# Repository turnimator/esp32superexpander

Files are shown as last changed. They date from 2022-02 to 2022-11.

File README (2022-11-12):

ESP32Superexpander.2ndattempt  - Previous hardware definition (KiCad) files
ESP32forth-7-Superexpander-0.1 - Arduino sketch containing a Superexpander ESPforth version
ESP32superexpander       -  The current Kicad files
Superexpander            - Arduino library for Suoerexpander
SuperExpander.odt        - A description of the project
superexpanderSupport.c   - Code to add to ESP32forth 

A document explaining the Forth code:

https://docs.google.com/document/d/1MlfXAm6yeVxjHgzF-E0LGG0kIZ7gFkiAXZAdYF-DrEk/edit?usp=sharing

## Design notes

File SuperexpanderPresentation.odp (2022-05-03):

## Requirements

- If your robot about to crash or drive off an edge, it must stop immediately
  For this you need IR sensors all around the the body, and ideally, underneath as well.
- In order to keep the robot from veering left or right, you need to know how far each wheel has traveled
  For this you need at least two disc encoders with optical sensors
- As your project progresses, you’ll want to add more features.
  For less than 8$, you can get a box with 37 sensors, most of which could be useful, or at least fun to add.
  Buzzers, Movement detectors (are the wheels spinning?), relays, color detectors (for line following and more), tilt switches, temperature sensors, sound detectors, shock detectors, humidity detectors (we don’t want to get wet!)
  Combining multiple input types, you can make inferences about the state of the robot and its environment.
  The more capabilities you add, the more awesome your robot becomes
- However ...

## Limitations

- … the ESP32 has 36 IO pins This may seem like a lot at first, but as you add sensors, distance measuring, GPS, … you’ll find the number of free pins dwindeling faster than the money in an average pensioner’s bank account
- In order to connect all your devices to the ESP32, you will have to make some kind of mainboard anyway, so why not solve two problems at once?

## ESP32 Superexpander

The ESP32 Superexpander gives you

- 3 headers for VL53L0X laser distance meters
- 4 I²C headers
- 2 headers for wheel motion IR sensors
- 1 header for L298 or compatible motor driver
- 12 on-off outputs for relays, switches, …
- 8 on-off inputs for sensors
- 12 breakouts for GPIO pins

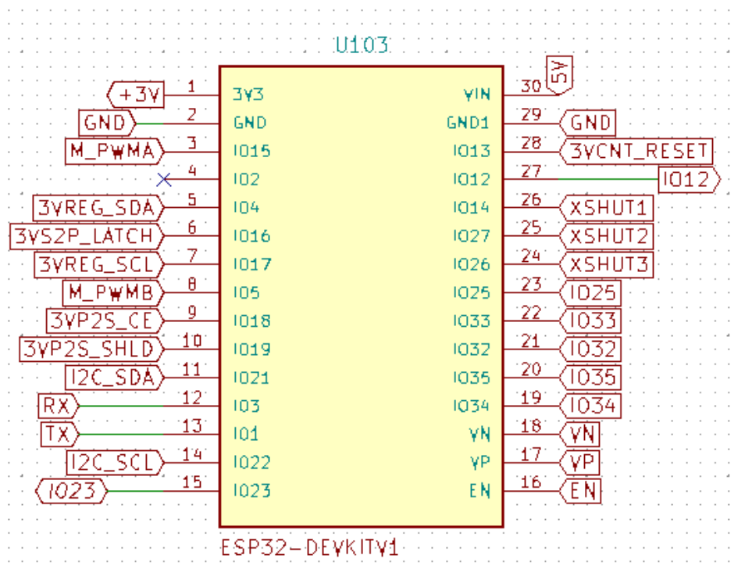
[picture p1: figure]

## Counters

- For some input, we need to know immediately if it goes active, e.g. an imminent crash or other catastrophe. An Interrupt Service Routine must set a variable and disable the motor before returning.
- For other inputs, like wheel motion, it’s enough to know how far we’ve traveled on each iteration. However, wheel motion arrives in tiny millimeter increments, and when driving at full speed, they arrive too fast for us to poll them. We need one interrupt handler for the left wheel and one for the right, updating two variables that we can read on each iteration. With all the other stuff that will be going on, reading a compass, reading lasers, communicating telemetry over UDP, avoiding obstacles, calculating trajectories, …. having two ISRs just for keeping track of wheel motion seems like an awful waste of resources.
- Why not offload the millimeter counting to a special purpose circuit like the 4060 and the read the count from a register on each iteration?

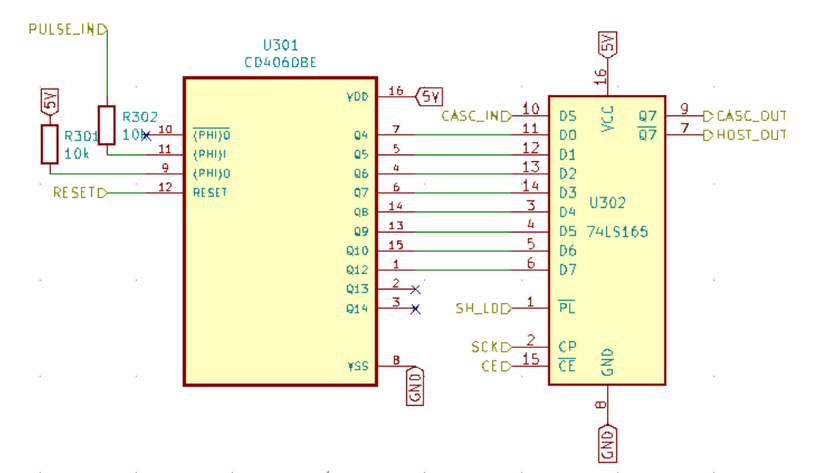
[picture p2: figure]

## Design

- Putting it all together in KiCad, you might get something like this

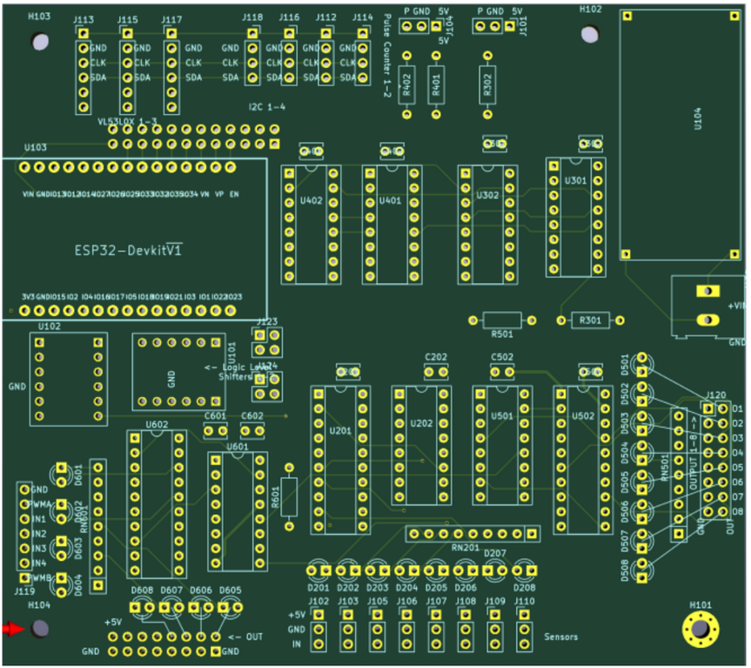
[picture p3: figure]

## BLINKENLIGHTS!!!

- … and, if you’re not careful when selecting resistor values for the LEDs, when you hook it up and turn on the power, it will look like this (which is what I wanted anyway because I’m crazy):

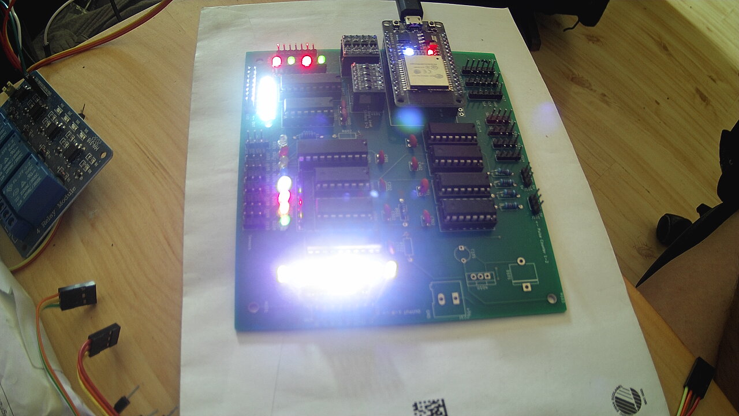
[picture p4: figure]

## Outputs

- Blink all outputs  Step through all 16 outputs, turning them on and off in sequence
  : blinkoutputs
  16 0 DO
  i outputon writeboard
  100 ms
  i outputoff writeboard
  100 ms
  LOOP
  ;

## Outputon

- The output number n must be on the stack
- If n is less than 8, set the nth bit in the value outreg1
- Else set the (8-n)th bit of outreg2
- Write the values of outreg1 and outreg2 to the board using writeS2P

: outputOn ( u -- )

dup 8 < IF

1 swap lshift outreg1 or to outreg1

ELSE

1 swap 8 - lshift outreg2 or to outreg2

THEN

;

## Gear_forward, Gear_backward

- Forward: Set bits 0 and 2, clear bits 1 and 3 in outreg1 without touching other bits
- Backward: Set bits 1 and 3, clear bits 0 and 2 in outreg1 without touching other bits

: gear_forward

binary

outreg1 10101111 and 10100000 or to outreg1

decimal

;

: gear_backward

binary

outreg1 01011111 and 01010000 or to outreg1

decimal

;

## WriteS2P

- Stack contains the two registers to be written
- Clear the LATCH
- Write the first
- Write the second
- Set the LATCH bit

S2P_LATCH 0 digitalWrite

8 0 DO

dup 1 and

S2P_SCL 0 digitalWrite

S2P_SDA swap digitalWrite

S2P_SCL 1 digitalWrite

1 RSHIFT

LOOP

Drop

…

S2P_LATCH 1 digitalWrite

## Inputs

- 2 counters
- 8 binary inputs
- Use readP2S to read (leaves three numbers on the stack)

## Showboard

- Show the status of the inputs
  NB: The inputs are inverted, 1 means 0 and 0 means 1. Counter value = 255-value.

: showBoard

readp2s

." Inputs " binary . cr

." Left wheel " decimal 255 swap - . cr

." Right wheel " 255 swap - . cr

;

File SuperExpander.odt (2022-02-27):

The ESP32 Superexpander

The ESP32 has 40 GPIO pins. If all you want to do is build a rover like the Forthmobile, that seems like a lot of pins, until you consider that 6 of them are used for the internal flash, one is used for debug, another is connected to the on-board LED, one will make the system fail if pulled high during boot, 4 are input only, and 4 of them produce a PWM signal at boot which might disturb your connected logic.

Only 14 pins don’t have any notes attached.

Out of these, you’ll need 2 for I2C clock and data, and if you’re planning to make use of the Forthmobile’s 3 VL53L0X laser distance sensors, you’re left with 9.

7 if you plan to use a GPS module. Perhaps you want two collision sensors at the front and two at the back? Now, you’ve got three pins left out of 40.

If you’re anything like me, you have a box full of cool sensors that you want to add: Movement detectors, sound, shock, and tilt detectors … temperature readers, line followers, buzzer and if you’re going to get anywhere at all, you need a motor controller, requiring an IN1, IN2, IN3, IN4 and two pwm pins.

A headlight switch would be nice to have as well, but you ran out of pins a couple of sensors ago.

Luckily, we can send data over a serial line to read to or write from an 8 bit register giving us 8 more pins minus the pins used for transmission, and if we cascade these registers, we get 16 extra pins instead of 8.

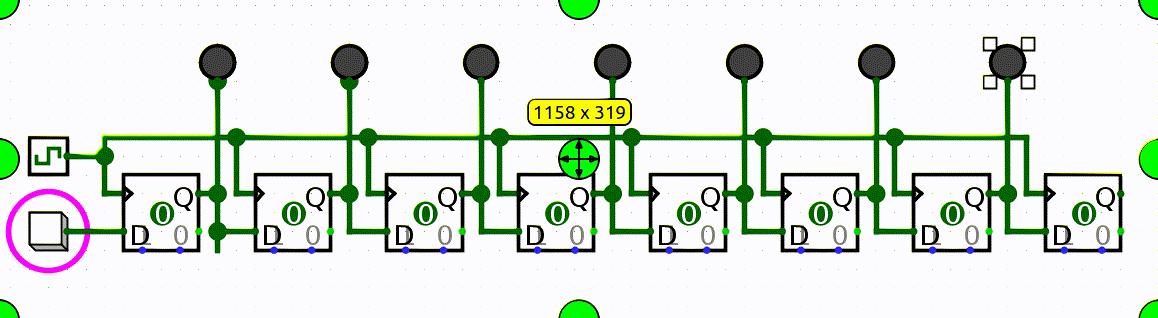
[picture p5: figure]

In the image above, when the square button in the lower left corner is pressed, a 1 is shifted in fron the left. When it’s released, a 0 is shifted in.

The ESP32 Superexpander uses five such registers, three 74LS165 for input and two 75LS595 for output.

Afferent flows

Two of the three 74165 input registers are connected to 4060 pulse counters.

Since the Superexpander is intended to be used as a main plate for a Forthmobile rover, the idea behind the counter registers is to let you keep track of your travel distance without using up two precious ESP32 interrupts.

The pulses are counted and stored in the 4060.

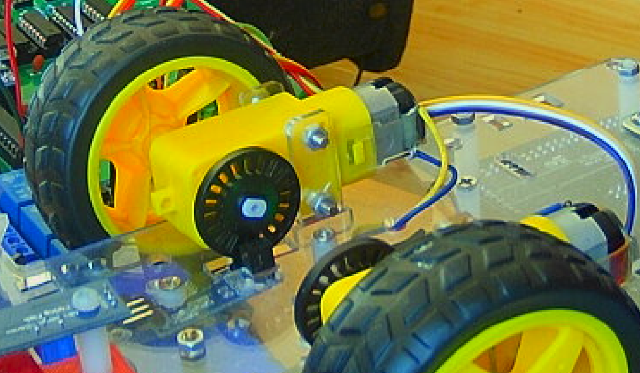
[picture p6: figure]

Figure 1: Mounted on the inside of the wheel is a disk with 24 slits in it. On the other side of the chassis there’s a pulse counter consisting of an LED and a photo transistor. Each time a slit passes over the LED, a pulse is generated.

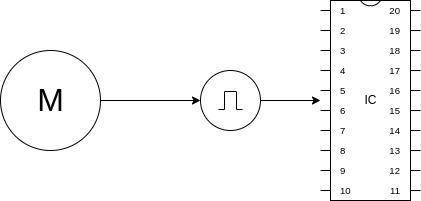
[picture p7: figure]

Whenever you want to read the value, you transfer the count from the 4060 to the 74165 using a LOAD signal (shown below as SH_LD) then read it serially into a variable inside the ESP32 using CLOCK and DATA signals, shown as SCK and HOST_OUT below.

Modules like the one above can be daisy-chained.

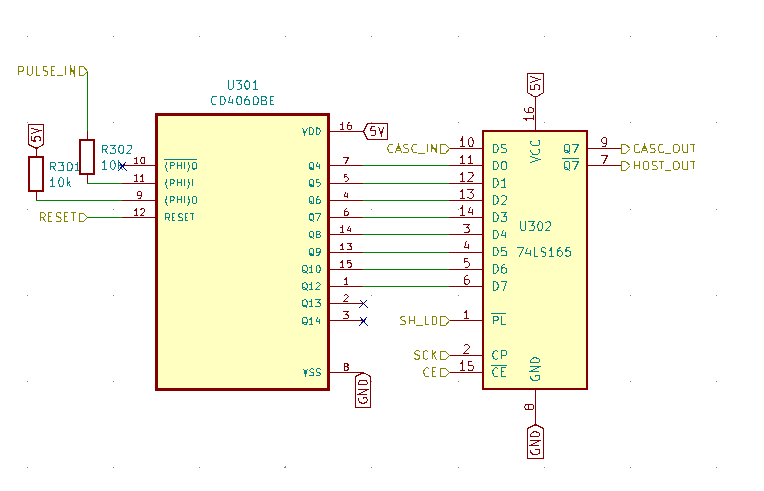
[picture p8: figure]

Figure 2: Counter module. When SH_LD is pulled LOW, data is transferred from the 4060 counter to the 74LS165 PISO register

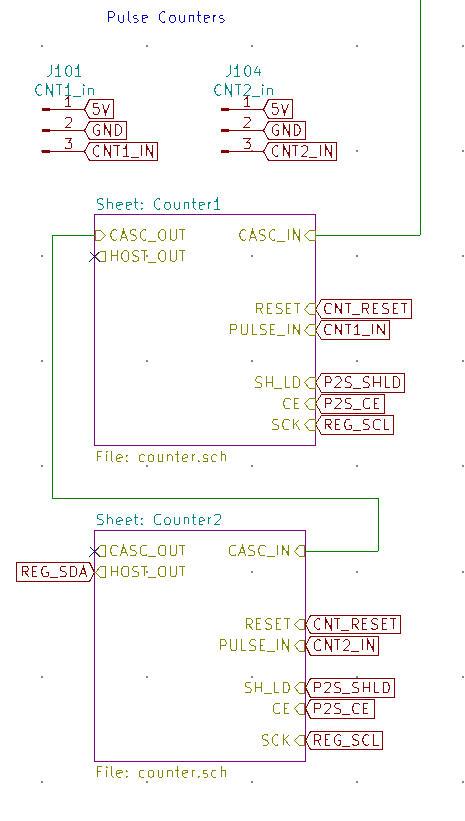
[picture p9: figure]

Figure 3: When daisy-chaining registers, serial output from one register is fed to the input of the next

The connectors J101 and J104 are meant for a pulse counter like the one below. The connections are as follows: VCC on the sensor to 5V on the module, GND to GND, and D0 CNT1_IN or CNT2_IN.

The A0 line is not used.

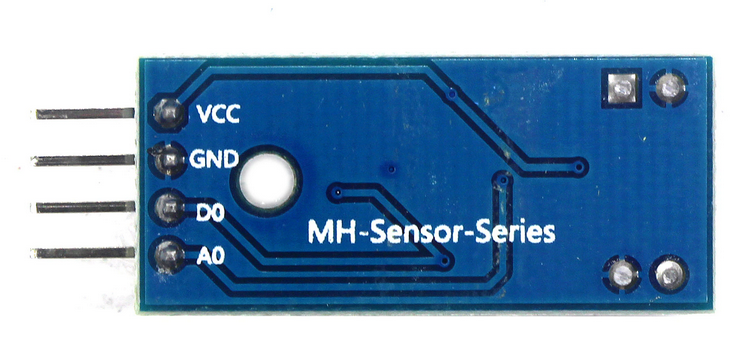
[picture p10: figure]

The CASC_IN line at the top of the counter module schematic comes from a sensor reading module.

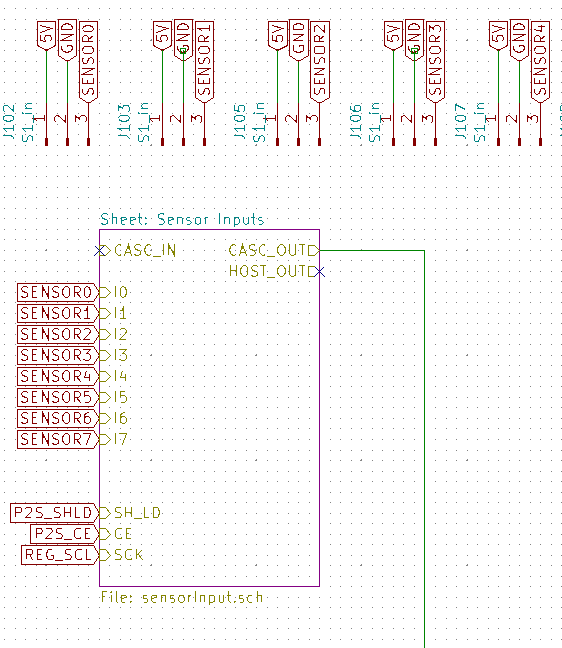
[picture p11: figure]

Figure 4: Here, you see the line CASC_OUT leaving the sensor schematic to enter as CASC_IN in the first counter module. The sensors are connected in the same way. Sensor VCC to 5V, GND to GND and the sensor output to one of the terminals labeled SENSOR0 through SENSOR7.

The inside of the module should be unsurprising. Instead of reading counter values, the 74165 reads the state of 8 input terminals, each corresponding to the output of one sensor.

The module also contains 8 LEDs that will light up on the board as soon as an input is activated.

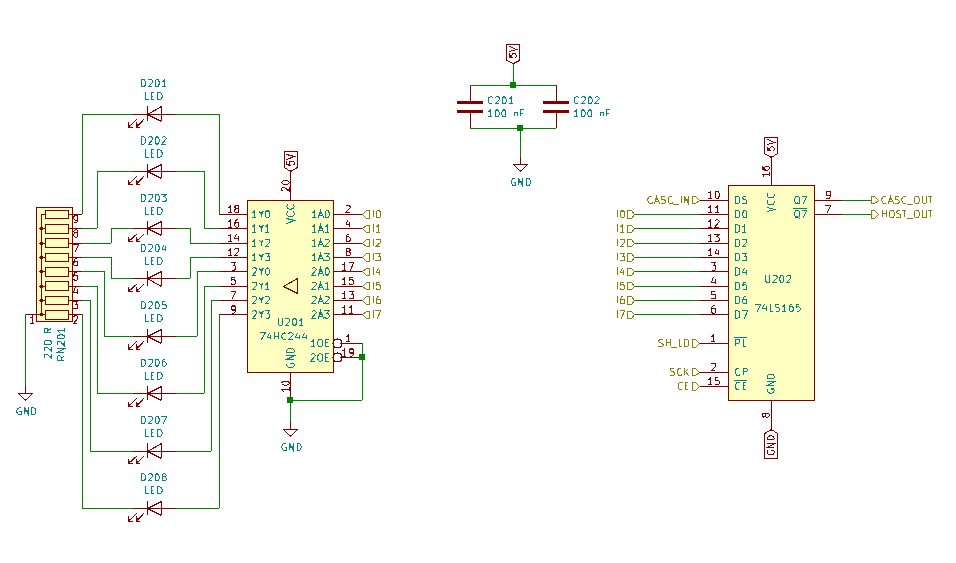
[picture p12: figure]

Figure 5: Sensor reading module. Data coming in on lines I0-I7 are split between the 74LS165 PISO register and an output buffer driving 7 LEDs.

Efferent flows

The output side consists of two output modules, cascaded in the same way as the input modules.

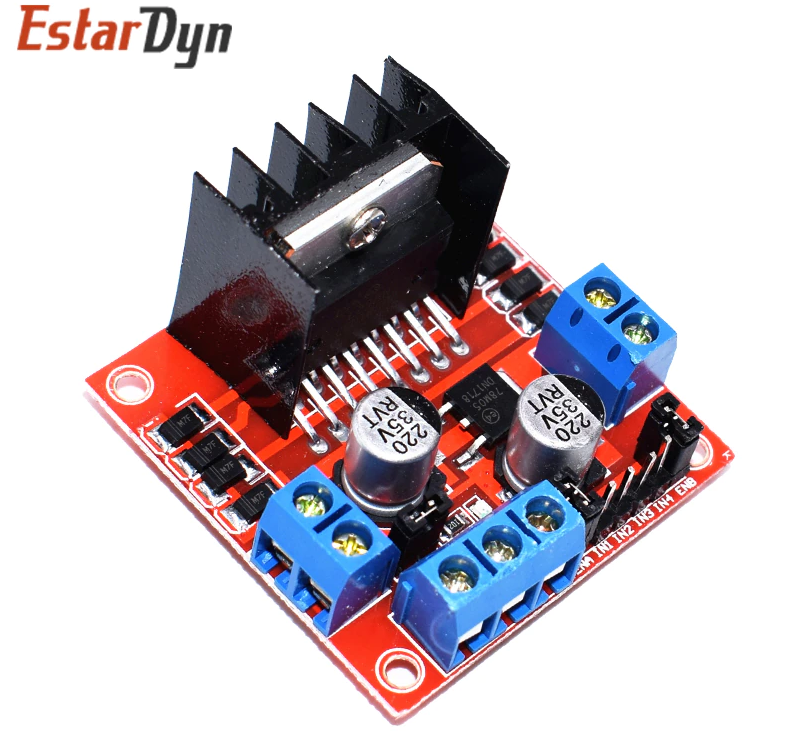
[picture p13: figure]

The connectors J120 and J121 give a total of 12 general purpose outputs plus 4x5V outputs.

The connector J119 is intended for an L298 motor driver shield, or any other shield with the same interface.

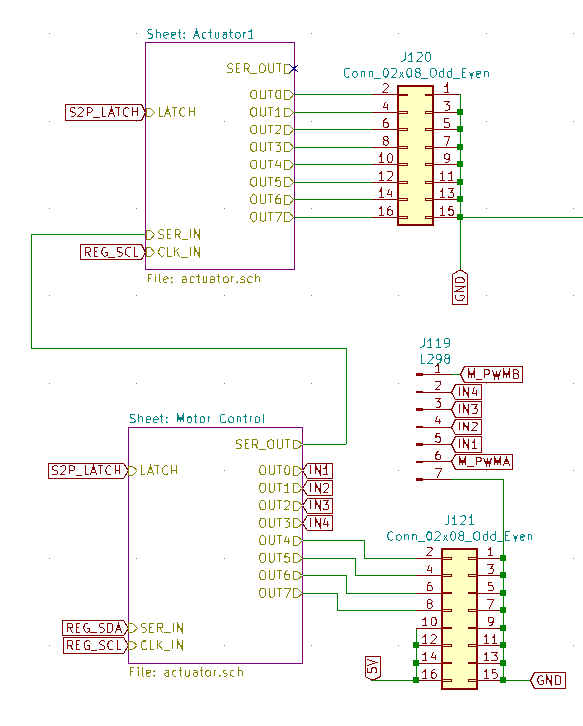
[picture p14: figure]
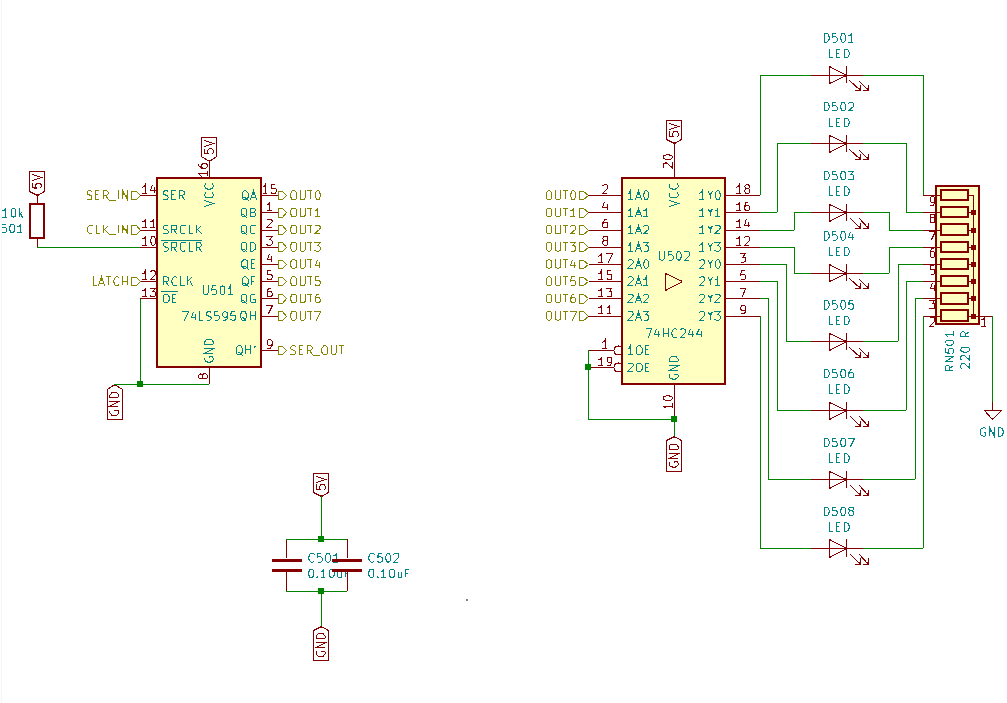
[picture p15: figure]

The outputs IN1 through IN4 get connected to IN1-IN4 on the shield, M_PWMA goes to ENA, and M_PWMB goes to ENB.

The inside of an actuator module is similar to that of the sensor module, with one LED per output for visual feedback.

Transformations

Last but not least, the star of the show: The ESP32 Devkit V1,

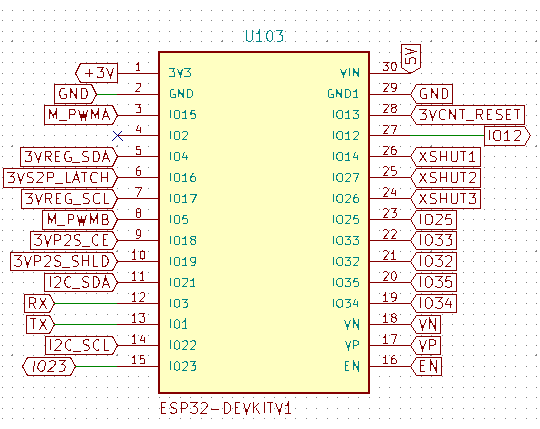
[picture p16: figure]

supported by two BOB-12009 level shifter modules to enable working with the more common 5V modules.

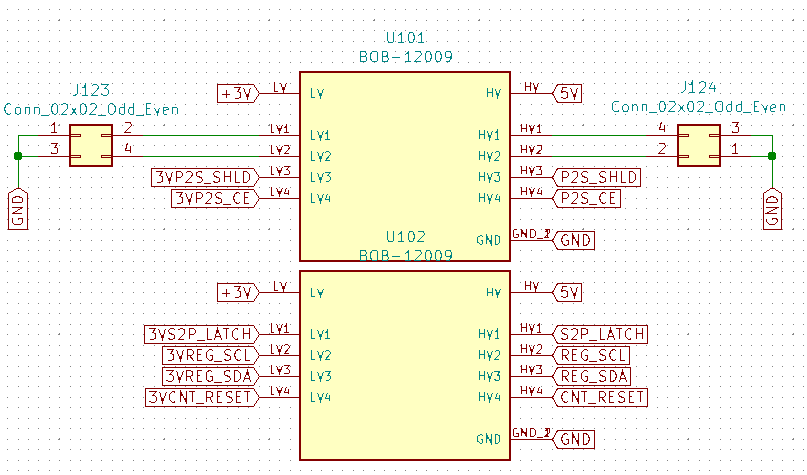
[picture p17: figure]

Figure 6: All the labels prefixed with 3V are connected to the ESP32 and the 3V side of the level shifters,

and the corresponding 5V side of the level shifter is connected to the register.

This is how the 3.3V ESP32 can drive 5V registers.

In addition to the connectors used for SIPO (serial-in, parallel out) and PISO registers, there are seven connectors giving access to the I2C bus. Three of them are intended for the LV53L0X laser distance sensor.

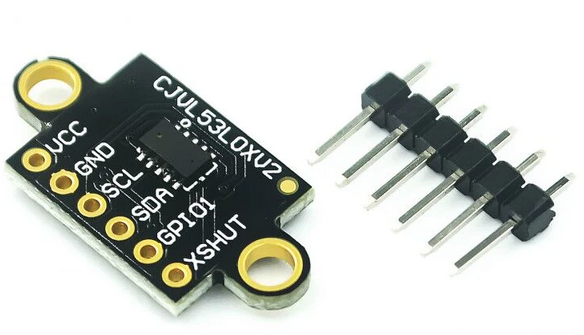
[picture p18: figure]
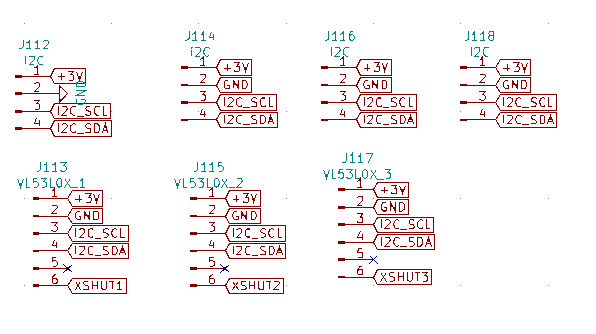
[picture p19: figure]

Putting it all together, the result becomes something like this:

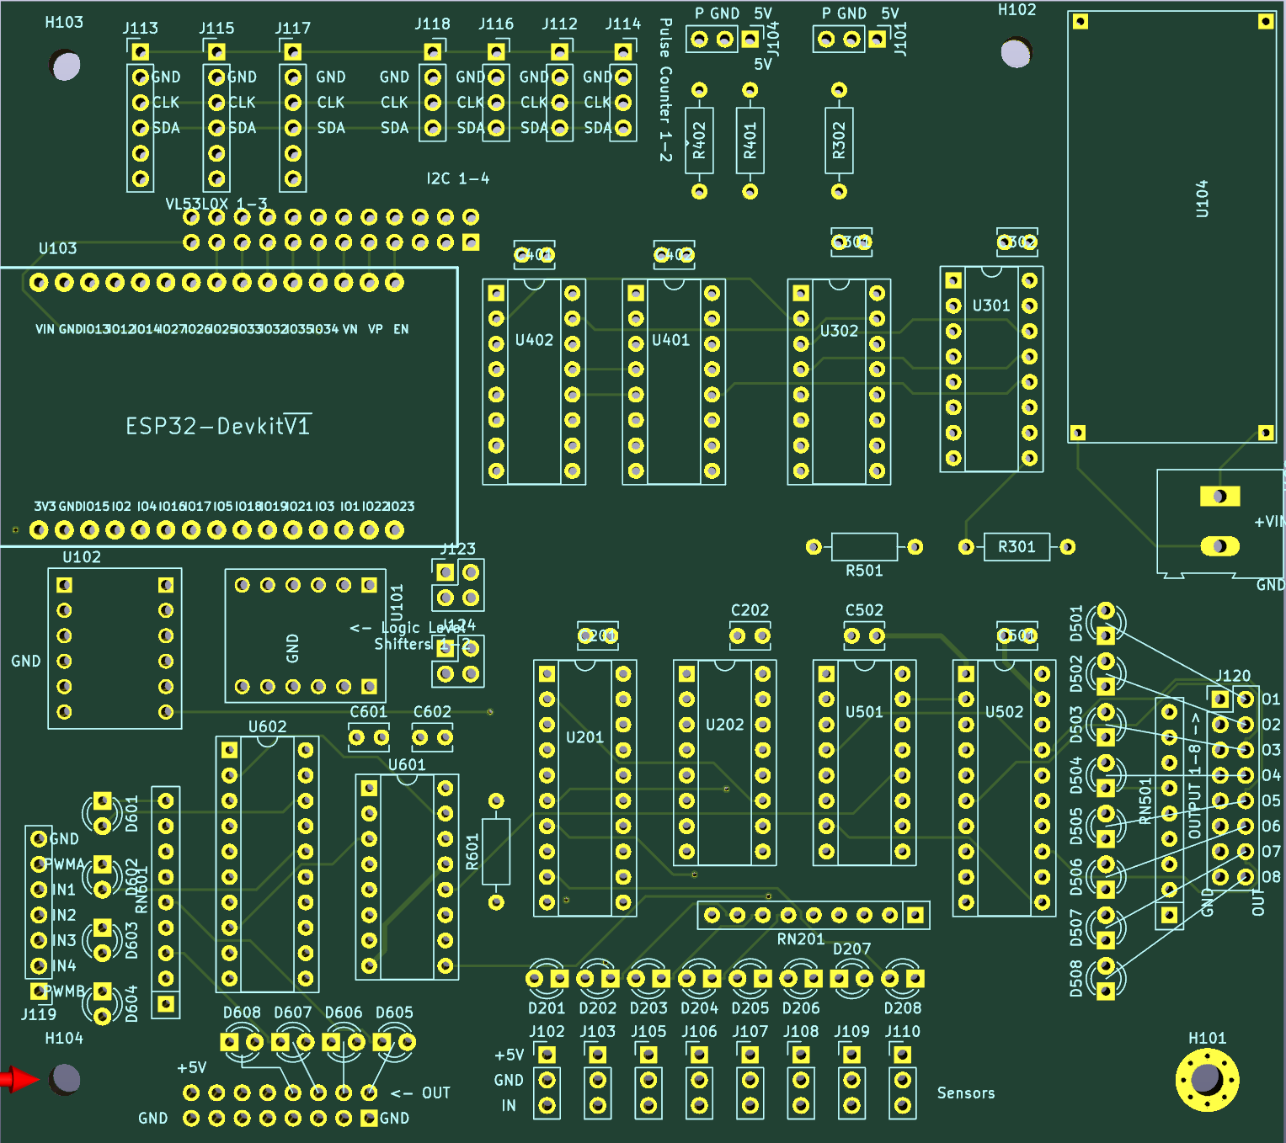
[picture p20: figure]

Directly above the ESP32 Devkit V1 module you find J111, a breakout of all the unused pins on the ESP32, 12 in all.

Programming

Constants

2 constant LED_BUILTIN

\ 74165 Parallel to serial

18 constant P2S_CE \ set high when P2S_SCK is HIGH to disable clock

19 constant P2S_SHLD \ Shift=1, load=0

17 constant P2S_SCK

23 constant P2S_SDA

\ 74595 Serial to parallel

4 constant S2P_SDA

16 constant S2P_LATCH \ aka RCLK

17 constant S2P_SCL

\ Motor control

15 constant M_PWMA

5 constant M_PWMB

\ LSB 0-3 of S2P give IN1-IN4 on the L298 motor controller connected to J15

21 constant I2C_SDA

22 constant I2C_SCL

13 constant CNT_RESET \ Reset the pulse counters on J21 and J22

\ VL53L0X uses I2C. To initialize, only keep one of these high and the

\ others LOW until the addresses are set. When the I2C address is set, all of these should be HIGH

14 constant XSHUT1

27 constant XSHUT2

26 constant XSHUT3

Setup

\ PISO REGISTERS

P2S_SHLD output pinMode

P2S_CE output pinMode

P2S_SCK output pinMode

P2S_SDA input pinMode

CNT_RESET output pinMode

CNT_RESET 0 digitalWrite 0 ms

CNT_RESET 1 digitalWrite 0 ms

CNT_RESET 0 digitalWrite

LED_BUILTIN output pinMode

P2S_SHLD output pinMode

P2S_CE output pinMode

P2S_SCK output pinMode

P2S_SDA input pinMode

Reading the PISO registers

: readP2S ( - n n n )

P2S_SHLD 0 digitalWrite 0 ms \ load data

P2S_SHLD 1 digitalWrite 0 ms \ prepare to shift

P2S_SCK 1 digitalWrite

P2S_CE 0 digitalWrite

P2S_SCK 0 digitalWrite

0

8 0 DO

1 LSHIFT

P2S_SCK 0 digitalWrite

P2S_SDA digitalRead OR

P2S_SCK 1 digitalWrite

LOOP

0

8 0 DO

1 LSHIFT

P2S_SCK 0 digitalWrite

P2S_SDA digitalRead OR

P2S_SCK 1 digitalWrite

LOOP

0

8 0 DO

1 LSHIFT

P2S_SCK 0 digitalWrite

P2S_SDA digitalRead OR

P2S_SCK 1 digitalWrite

LOOP

;

binary readp2s . . . decimal

11101011 11111011 11101111 ok

binary readp2s . . . decimal

11111011 11111011 11101111 ok

binary readp2s . . . decimal

11111111 11111011 11101111 ok

readp2s binary . decimal . . cr

11101011 251 239

ok

readp2s binary . decimal . . cr

11101011 249 239

ok

readp2s binary . decimal . . cr

11101011 249 239

ok

readp2s binary . decimal . . cr

11101011 247 239

Ok

Writing the SIPO registers

: writeS2P ( u u --)

S2P_LATCH 0 digitalWrite

8 0 DO

dup 1 and

S2P_SCL 0 digitalWrite

S2P_SDA swap digitalWrite

S2P_SCL 1 digitalWrite

1 RSHIFT

LOOP

drop

8 0 DO

dup 1 and

S2P_SCL 0 digitalWrite

S2P_SDA swap digitalWrite

S2P_SCL 1 digitalWrite

1 RSHIFT

LOOP

drop

S2P_LATCH 1 digitalWrite

;

Testing the SIPO registers (video) (https://youtu.be/Z3yySXJiUW0)

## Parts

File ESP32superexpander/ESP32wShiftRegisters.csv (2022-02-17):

Id | Designator | Package | Quantity | Designation | Supplier and ref
1 | J23 | BarrelJack_Wuerth_6941xx301002 | 1 | Jack-DC
2 | RN1 | R_Array_SIP9 | 1 | R_Network08
3 | D8,D7,D6,D5,D4,D3,D2,D1 | LED_D3.0mm | 8 | LED
4 | U14 | TO-220-3_Vertical | 1 | L7805
5 | U13,U11,U8 | DIP-16_W7.62mm_Socket | 3 | 74LS165
6 | U12 | DIP-18_W7.62mm_Socket | 1 | 74LS165
7 | U10,U9 | DIP-16_W7.62mm_Socket | 2 | CD4060BE
8 | U7,U6 | CONV_BOB-12009 | 2 | BOB-12009
9 | U5 | ESP32-DEVKITV1 | 1 | ESP32DEVKITV1
10 | U4,U3 | DIP-20_W7.62mm_Socket | 2 | 74HC244
11 | U2,U1 | DIP-16_W7.62mm_Socket | 2 | 74LS595
12 | R8,R7,R6,R5,R4,R3,R2,R1 | R_Axial_DIN0207_L6.3mm_D2.5mm_P10.16mm_Horizontal | 8 | 10k
13 | J22 | PinHeader_1x03_P2.54mm_Vertical | 1 | CNT2_in
14 | J21 | PinHeader_1x03_P2.54mm_Vertical | 1 | CNT1_in
15 | J20 | PinHeader_1x03_P2.54mm_Vertical | 1 | S8_in
16 | J19,J14,J7 | PinSocket_1x04_P2.54mm_Vertical | 3 | I2C
17 | J18 | PinHeader_1x03_P2.54mm_Vertical | 1 | S7_in
18 | J17 | PinSocket_1x08_P2.54mm_Vertical | 1 | EN VP VN 34 35 32 33 25
19 | J16 | PinHeader_1x06_P2.54mm_Vertical | 1 | VL53L0X_3
20 | J15 | PinHeader_1x07_P2.54mm_Vertical | 1 | L298
21 | J13 | PinHeader_1x03_P2.54mm_Vertical | 1 | S6_in
22 | J12 | PinHeader_1x06_P2.54mm_Vertical | 1 | VL53L0X_2
23 | J11 | PinSocket_1x04_P2.54mm_Vertical | 1 | i2C
24 | J10 | PinHeader_1x03_P2.54mm_Vertical | 1 | S5_in
25 | J9 | PinHeader_1x03_P2.54mm_Vertical | 1 | S4_in
26 | J8 | PinHeader_1x06_P2.54mm_Vertical | 1 | VL53L0X_1
27 | J6 | PinHeader_1x03_P2.54mm_Vertical | 1 | S3_in
28 | J5 | PinHeader_1x03_P2.54mm_Vertical | 1 | S2_in
29 | J4 | PinHeader_1x03_P2.54mm_Vertical | 1 | S1_in
30 | J3 | PinSocket_1x08_P2.54mm_Vertical | 1 | INP1-8
31 | J2 | PinSocket_1x04_P2.54mm_Vertical | 1 | OUT9-12
32 | J1 | PinSocket_1x08_P2.54mm_Vertical | 1 | OUT1-8
33 | H4,H2,H1 | MountingHole_3.2mm_M3 | 3 | MountingHole_Pad
34 | D9 | DIOB_GBJ2506 | 1 | GBJ2510
35 | C13 | CP_Radial_Tantal_D5.5mm_P5.00mm | 1 | 100uF
36 | C12,C11,C10,C9,C8,C7,C6,C5,C4,C3,C2,C1 | C_Disc_D3.8mm_W2.6mm_P2.50mm | 12 | 0.10uF

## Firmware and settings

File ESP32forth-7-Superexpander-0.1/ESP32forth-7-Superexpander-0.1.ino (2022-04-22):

/*
 * Copyright 2021 Bradley D. Nelson
 *
 * Licensed under the Apache License, Version 2.0 (the "License");
 * you may not use this file except in compliance with the License.
 * You may obtain a copy of the License at
 *
 *     http://www.apache.org/licenses/LICENSE-2.0
 *
 * Unless required by applicable law or agreed to in writing, software
 * distributed under the License is distributed on an "AS IS" BASIS,
 * WITHOUT WARRANTIES OR CONDITIONS OF ANY KIND, either express or implied.
 * See the License for the specific language governing permissions and
 * limitations under the License.
*/

/*
 * ESP32forth v7.0.5.4
 * Revision: c7474b756beb296dd1316d241a218cd4e4041b77
 */

#include <inttypes.h>
#include <stdint.h>
#include <stdlib.h>
#include <string.h>

typedef intptr_t cell_t;
typedef uintptr_t ucell_t;

#define Y(op, code) X(#op, id ## op, code)
#define NIP (--sp)
#define NIPn(n) (sp -= (n))
#define DROP (tos = *sp--)
#define DROPn(n) (NIPn(n-1), DROP)
#define DUP (*++sp = tos)
#define PUSH DUP; tos = (cell_t)
#define COMMA(n) *g_sys.heap++ = (n)
#define DOIMMEDIATE() (*g_sys.current)[-1] |= IMMEDIATE
#define UNSMUDGE() (*g_sys.current)[-1] &= ~SMUDGE
#define DOES(ip) **g_sys.current = (cell_t) ADDR_DODOES; (*g_sys.current)[1] = (cell_t) ip
#define PARK DUP; *++rp = (cell_t) sp; *++rp = (cell_t) ip

#ifndef SSMOD_FUNC
# if __SIZEOF_POINTER__ == 8
typedef __int128_t dcell_t;
# elif __SIZEOF_POINTER__ == 4 || defined(_M_IX86)
typedef int64_t dcell_t;
# else
#  error "unsupported cell size"
# endif
# define SSMOD_FUNC dcell_t d = (dcell_t) *sp * (dcell_t) sp[-1]; \
                    --sp; cell_t a = (cell_t) (d < 0 ? ~(~d / tos) : d / tos); \
                    *sp = (cell_t) (d - ((dcell_t) a) * tos); tos = a
#endif

#define OPCODE_LIST \
  X("0=", ZEQUAL, tos = !tos ? -1 : 0) \
  X("0<", ZLESS, tos = (tos|0) < 0 ? -1 : 0) \
  X("+", PLUS, tos += *sp--) \
  X("U/MOD", USMOD, w = *sp; *sp = (ucell_t) w % (ucell_t) tos; \
                    tos = (ucell_t) w / (ucell_t) tos) \
  X("*/MOD", SSMOD, SSMOD_FUNC) \
  Y(LSHIFT, tos = (*sp-- << tos)) \
  Y(RSHIFT, tos = (*sp-- >> tos)) \
  Y(AND, tos &= *sp--) \
  Y(OR, tos |= *sp--) \
  Y(XOR, tos ^= *sp--) \
  Y(DUP, DUP) \
  Y(SWAP, w = tos; tos = *sp; *sp = w) \
  Y(OVER, DUP; tos = sp[-1]) \
  Y(DROP, DROP) \
  X("@", AT, tos = *(cell_t *) tos) \
  X("L@", LAT, tos = *(int32_t *) tos) \
  X("C@", CAT, tos = *(uint8_t *) tos) \
  X("!", STORE, *(cell_t *) tos = *sp--; DROP) \
  X("L!", LSTORE, *(int32_t *) tos = *sp--; DROP) \
  X("C!", CSTORE, *(uint8_t *) tos = *sp--; DROP) \
  X("SP@", SPAT, DUP; tos = (cell_t) sp) \
  X("SP!", SPSTORE, sp = (cell_t *) tos; DROP) \
  X("RP@", RPAT, DUP; tos = (cell_t) rp) \
  X("RP!", RPSTORE, rp = (cell_t *) tos; DROP) \
  X(">R", TOR, *++rp = tos; DROP) \
  X("R>", FROMR, DUP; tos = *rp; --rp) \
  X("R@", RAT, DUP; tos = *rp) \
  Y(EXECUTE, w = tos; DROP; JMPW) \
  Y(BRANCH, ip = (cell_t *) *ip) \
  Y(0BRANCH, if (!tos) ip = (cell_t *) *ip; else ++ip; DROP) \
  Y(DONEXT, *rp = *rp - 1; if (~*rp) ip = (cell_t *) *ip; else (--rp, ++ip)) \
  Y(DOLIT, DUP; tos = *ip++) \
  Y(ALITERAL, COMMA(g_sys.DOLIT_XT); COMMA(tos); DROP) \
  Y(CELL, DUP; tos = sizeof(cell_t)) \
  Y(FIND, tos = find((const char *) *sp, tos); --sp) \
  Y(PARSE, DUP; tos = parse(tos, sp)) \
  X("S>NUMBER?", CONVERT, tos = convert((const char *) *sp, tos, sp); \
                          if (!tos) --sp) \
  Y(CREATE, DUP; DUP; tos = parse(32, sp); \
            create((const char *) *sp, tos, 0, ADDR_DOCREATE); \
            COMMA(0); DROPn(2)) \
  X("DOES>", DOES, DOES(ip); ip = (cell_t *) *rp; --rp) \
  Y(IMMEDIATE, DOIMMEDIATE()) \
  X("'SYS", SYS, DUP; tos = (cell_t) &g_sys) \
  Y(YIELD, PARK; return rp) \
  X(":", COLON, DUP; DUP; tos = parse(32, sp); \
                create((const char *) *sp, tos, SMUDGE, ADDR_DOCOLON); \
                g_sys.state = -1; --sp; DROP) \
  Y(EVALUATE1, DUP; sp = evaluate1(sp); w = *sp--; DROP; if (w) JMPW) \
  Y(EXIT, ip = (cell_t *) *rp--) \
  X(";", SEMICOLON, UNSMUDGE(); COMMA(g_sys.DOEXIT_XT); g_sys.state = 0) \


#define SET tos = (cell_t)

#define n0 tos
#define n1 (*sp)
#define n2 sp[-1]
#define n3 sp[-2]
#define n4 sp[-3]
#define n5 sp[-4]
#define n6 sp[-5]
#define n7 sp[-6]
#define n8 sp[-7]
#define n9 sp[-8]
#define n10 sp[-9]

#define a0 ((void *) tos)
#define a1 (*(void **) &n1)
#define a2 (*(void **) &n2)
#define a3 (*(void **) &n3)
#define a4 (*(void **) &n4)
#define a5 (*(void **) &n5)
#define a6 (*(void **) &n6)

#define b0 ((uint8_t *) tos)
#define b1 (*(uint8_t **) &n1)
#define b2 (*(uint8_t **) &n2)
#define b3 (*(uint8_t **) &n3)
#define b4 (*(uint8_t **) &n4)
#define b5 (*(uint8_t **) &n5)
#define b6 (*(uint8_t **) &n6)

#define c0 ((char *) tos)
#define c1 (*(char **) &n1)
#define c2 (*(char **) &n2)
#define c3 (*(char **) &n3)
#define c4 (*(char **) &n4)
#define c5 (*(char **) &n5)
#define c6 (*(char **) &n6)



// For now, default on several options.
#define ENABLE_SPIFFS_SUPPORT
#define ENABLE_WIFI_SUPPORT
#define ENABLE_MDNS_SUPPORT
#define ENABLE_WEBSERVER_SUPPORT
#define ENABLE_SDCARD_SUPPORT
#define ENABLE_I2C_SUPPORT
#define ENABLE_SOCKETS_SUPPORT
#define ENABLE_FREERTOS_SUPPORT
#define ENABLE_INTERRUPTS_SUPPORT
#define ENABLE_SUPEREXPANDER_SUPPORT

// Uncomment this #define for OLED Support.
// You will need to install these libraries from the Library Manager:
//   Adafruit SSD1306
//   Adafruit GFX Library
//   Adafruit BusIO
//#define ENABLE_OLED_SUPPORT

// For now assume only boards with PSRAM (ESP32-CAM)
// will want SerialBluetooth (very large) and camera support.
// Other boards can support these if they're set to a larger
// parition size. But it's unclear the best way to configure this.
#ifdef BOARD_HAS_PSRAM
# define ENABLE_CAMERA_SUPPORT
# define ENABLE_SERIAL_BLUETOOTH_SUPPORT
#endif

#ifdef ENABLE_WEBSERVER_SUPPORT
# include "WebServer.h"
#endif

#include <errno.h>
#include <unistd.h>
#include <fcntl.h>
#include <sys/types.h>
#include <sys/stat.h>
#include <sys/select.h>

#if defined(ESP32)
# define HEAP_SIZE (100 * 1024)
# define STACK_SIZE 512
#elif defined(ESP8266)
# define HEAP_SIZE (40 * 1024)
# define STACK_SIZE 512
#else
# define HEAP_SIZE 2 * 1024
# define STACK_SIZE 32
#endif
#define INTERRUPT_STACK_CELLS 64

#define PLATFORM_OPCODE_LIST \
  /* Memory Allocation */ \
  Y(MALLOC, SET malloc(n0)) \
  Y(SYSFREE, free(a0); DROP) \
  Y(REALLOC, SET realloc(a1, n0); NIP) \
  Y(heap_caps_malloc, SET heap_caps_malloc(n1, n0); NIP) \
  Y(heap_caps_free, heap_caps_free(a0); DROP) \
  Y(heap_caps_realloc, \
      tos = (cell_t) heap_caps_realloc(a2, n1, n0); NIPn(2)) \
  /* Serial */ \
  X("Serial.begin", SERIAL_BEGIN, Serial.begin(tos); DROP) \
  X("Serial.end", SERIAL_END, Serial.end()) \
  X("Serial.available", SERIAL_AVAILABLE, PUSH Serial.available()) \
  X("Serial.readBytes", SERIAL_READ_BYTES, n0 = Serial.readBytes(b1, n0); NIP) \
  X("Serial.write", SERIAL_WRITE, n0 = Serial.write(b1, n0); NIP) \
  X("Serial.flush", SERIAL_FLUSH, Serial.flush()) \
  /* Pins and PWM */ \
  Y(pinMode, pinMode(n1, n0); DROPn(2)) \
  Y(digitalWrite, digitalWrite(n1, n0); DROPn(2)) \
  Y(digitalRead, n0 = digitalRead(n0)) \
  Y(analogRead, n0 = analogRead(n0)) \
  Y(pulseIn, n0 = pulseIn(n2, n1, n0); NIPn(2)) \
  Y(dacWrite, dacWrite(n1, n0); DROPn(2)) \
  Y(ledcSetup, \
      n0 = (cell_t) (1000000 * ledcSetup(n2, n1 / 1000.0, n0)); NIPn(2)) \
  Y(ledcAttachPin, ledcAttachPin(n1, n0); DROPn(2)) \
  Y(ledcDetachPin, ledcDetachPin(n0); DROP) \
  Y(ledcRead, n0 = ledcRead(n0)) \
  Y(ledcReadFreq, n0 = (cell_t) (1000000 * ledcReadFreq(n0))) \
  Y(ledcWrite, ledcWrite(n1, n0); DROPn(2)) \
  Y(ledcWriteTone, \
      n0 = (cell_t) (1000000 * ledcWriteTone(n1, n0 / 1000.0)); NIP) \
  Y(ledcWriteNote, \
      tos = (cell_t) (1000000 * ledcWriteNote(n2, (note_t) n1, n0)); NIPn(2)) \
  /* General System */ \
  X("MS-TICKS", MS_TICKS, PUSH millis()) \
  X("RAW-YIELD", RAW_YIELD, yield()) \
  Y(TERMINATE, exit(n0)) \
  /* File words */ \
  X("R/O", R_O, PUSH O_RDONLY) \
  X("R/W", R_W, PUSH O_RDWR) \
  X("W/O", W_O, PUSH O_WRONLY) \
  Y(BIN, ) \
  X("CLOSE-FILE", CLOSE_FILE, tos = close(tos); tos = tos ? errno : 0) \
  X("FLUSH-FILE", FLUSH_FILE, fsync(tos); /* fsync has no impl and returns ENOSYS :-( */ tos = 0) \
  X("OPEN-FILE", OPEN_FILE, cell_t mode = n0; DROP; cell_t len = n0; DROP; \
    memcpy(filename, a0, len); filename[len] = 0; \
    n0 = open(filename, mode, 0777); PUSH n0 < 0 ? errno : 0) \
  X("CREATE-FILE", CREATE_FILE, cell_t mode = n0; DROP; cell_t len = n0; DROP; \
    memcpy(filename, a0, len); filename[len] = 0; \
    n0 = open(filename, mode | O_CREAT | O_TRUNC); PUSH n0 < 0 ? errno : 0) \
  X("DELETE-FILE", DELETE_FILE, cell_t len = n0; DROP; \
    memcpy(filename, a0, len); filename[len] = 0; \
    n0 = unlink(filename); n0 = n0 ? errno : 0) \
  X("WRITE-FILE", WRITE_FILE, cell_t fd = n0; DROP; cell_t len = n0; DROP; \
    n0 = write(fd, a0, len); n0 = n0 != len ? errno : 0) \
  X("READ-FILE", READ_FILE, cell_t fd = n0; DROP; cell_t len = n0; DROP; \
    n0 = read(fd, a0, len); PUSH n0 < 0 ? errno : 0) \
  X("FILE-POSITION", FILE_POSITION, \
    n0 = (cell_t) lseek(n0, 0, SEEK_CUR); PUSH n0 < 0 ? errno : 0) \
  X("REPOSITION-FILE", REPOSITION_FILE, cell_t fd = n0; DROP; \
    n0 = (cell_t) lseek(fd, tos, SEEK_SET); n0 = n0 < 0 ? errno : 0) \
  X("RESIZE-FILE", RESIZE_FILE, cell_t fd = n0; DROP; n0 = ResizeFile(fd, tos)) \
  X("FILE-SIZE", FILE_SIZE, struct stat st; w = fstat(n0, &st); \
    n0 = (cell_t) st.st_size; PUSH w < 0 ? errno : 0) \
  OPTIONAL_SPIFFS_SUPPORT \
  OPTIONAL_WIFI_SUPPORT \
  OPTIONAL_MDNS_SUPPORT \
  OPTIONAL_WEBSERVER_SUPPORT \
  OPTIONAL_SDCARD_SUPPORT \
  OPTIONAL_I2C_SUPPORT \
  OPTIONAL_SERIAL_BLUETOOTH_SUPPORT \
  OPTIONAL_CAMERA_SUPPORT \
  OPTIONAL_SOCKETS_SUPPORT \
  OPTIONAL_FREERTOS_SUPPORT \
  OPTIONAL_INTERRUPTS_SUPPORT \
  OPTIONAL_OLED_SUPPORT \
  OPTIONAL_SUPEREXPANDER_SUPPORT \

#ifdef ENABLE_SUPEREXPANDER_SUPPORT
#include "Superexpander.h"
Superexpander se;
#define OPTIONAL_SUPEREXPANDER_SUPPORT \
X("se.setSwitch", se_setSwitch, se.setSwitch(n1, n0); NIPn(2)) \
X("se.setMotor", se_setMotor, se.setMotor(n1, n0); NIPn(2)) \
X("se.getSensor", se_getSensor, n0 = se.getSensor(n0)) \
X("se.getCounter1", se_getCounter1, n0 = se.getCounter1()) \
X("se.getCounter2", se_getCounter2, n0 = se.getCounter2()) \
X("se.writeBoard", se_writeBoard, se.writeBoard()) \
X("se.readBoard", se_readBoard, se.readBoard()) \
X("se.begin", se_begin, se.begin()) 
#else
#define OPTIONAL_SUPEREXPANDER_SUPPORT
#endif


#ifndef ENABLE_SPIFFS_SUPPORT
// Provide a default failing SPIFFS.begin
# define OPTIONAL_SPIFFS_SUPPORT \
  X("SPIFFS.begin", SPIFFS_BEGIN, NIPn(2); n0 = 0)
#else
# include "SPIFFS.h"
# define OPTIONAL_SPIFFS_SUPPORT \
  X("SPIFFS.begin", SPIFFS_BEGIN, \
      tos = SPIFFS.begin(n2, c1, n0); NIPn(2)) \
  X("SPIFFS.end", SPIFFS_END, SPIFFS.end()) \
  X("SPIFFS.format", SPIFFS_FORMAT, PUSH SPIFFS.format()) \
  X("SPIFFS.totalBytes", SPIFFS_TOTAL_BYTES, PUSH SPIFFS.totalBytes()) \
  X("SPIFFS.usedBytes", SPIFFS_USED_BYTES, PUSH SPIFFS.usedBytes())
#endif

#ifndef ENABLE_FREERTOS_SUPPORT
# define OPTIONAL_FREERTOS_SUPPORT
#else
# include "freertos/FreeRTOS.h"
# include "freertos/task.h"
# define OPTIONAL_FREERTOS_SUPPORT \
  Y(vTaskDelete, vTaskDelete((TaskHandle_t) n0); DROP) \
  Y(xTaskCreatePinnedToCore, n0 = xTaskCreatePinnedToCore((TaskFunction_t) a6, c5, n4, a3, (UBaseType_t) n2, (TaskHandle_t *) a1, (BaseType_t) n0); NIPn(6)) \
  Y(xPortGetCoreID, PUSH xPortGetCoreID())
#endif

#ifndef ENABLE_INTERRUPTS_SUPPORT
# define OPTIONAL_INTERRUPTS_SUPPORT
#else
# include "esp_intr_alloc.h"
# include "driver/timer.h"
# include "driver/gpio.h"
# define OPTIONAL_INTERRUPTS_SUPPORT \
  Y(gpio_config, n0 = gpio_config((const gpio_config_t *) a0)) \
  Y(gpio_reset_pin, n0 = gpio_reset_pin((gpio_num_t) n0)) \
  Y(gpio_set_intr_type, n0 = gpio_set_intr_type((gpio_num_t) n1, (gpio_int_type_t) n0); NIP) \
  Y(gpio_intr_enable, n0 = gpio_intr_enable((gpio_num_t) n0)) \
  Y(gpio_intr_disable, n0 = gpio_intr_disable((gpio_num_t) n0)) \
  Y(gpio_set_level, n0 = gpio_set_level((gpio_num_t) n1, n0); NIP) \
  Y(gpio_get_level, n0 = gpio_get_level((gpio_num_t) n0)) \
  Y(gpio_set_direction, n0 = gpio_set_direction((gpio_num_t) n1, (gpio_mode_t) n0); NIP) \
  Y(gpio_set_pull_mode, n0 = gpio_set_pull_mode((gpio_num_t) n1, (gpio_pull_mode_t) n0); NIP) \
  Y(gpio_wakeup_enable, n0 = gpio_wakeup_enable((gpio_num_t) n1, (gpio_int_type_t) n0); NIP) \
  Y(gpio_wakeup_disable, n0 = gpio_wakeup_disable((gpio_num_t) n0)) \
  Y(gpio_pullup_en, n0 = gpio_pullup_en((gpio_num_t) n0)) \
  Y(gpio_pullup_dis, n0 = gpio_pullup_dis((gpio_num_t) n0)) \
  Y(gpio_pulldown_en, n0 = gpio_pulldown_en((gpio_num_t) n0)) \
  Y(gpio_pulldown_dis, n0 = gpio_pulldown_dis((gpio_num_t) n0)) \
  Y(gpio_hold_en, n0 = gpio_hold_en((gpio_num_t) n0)) \
  Y(gpio_hold_dis, n0 = gpio_hold_dis((gpio_num_t) n0)) \
  Y(gpio_deep_sleep_hold_en, gpio_deep_sleep_hold_en()) \
  Y(gpio_deep_sleep_hold_dis, gpio_deep_sleep_hold_dis()) \
  Y(gpio_install_isr_service, n0 = gpio_install_isr_service(n0)) \
  Y(gpio_uninstall_isr_service, gpio_uninstall_isr_service()) \
  Y(gpio_isr_handler_add, n0 = GpioIsrHandlerAdd(n2, n1, n0); NIPn(2)) \
  Y(gpio_isr_handler_remove, n0 = gpio_isr_handler_remove((gpio_num_t) n0)) \
  Y(gpio_set_drive_capability, n0 = gpio_set_drive_capability((gpio_num_t) n1, (gpio_drive_cap_t) n0); NIP) \
  Y(gpio_get_drive_capability, n0 = gpio_get_drive_capability((gpio_num_t) n1, (gpio_drive_cap_t *) a0); NIP) \
  Y(esp_intr_alloc, n0 = EspIntrAlloc(n4, n3, n2, n1, a0); NIPn(4)) \
  Y(esp_intr_free, n0 = esp_intr_free((intr_handle_t) n0)) \
  Y(timer_isr_register, n0 = TimerIsrRegister(n5, n4, n3, n2, n1, a0); NIPn(5))
#endif

#ifndef ENABLE_CAMERA_SUPPORT
# define OPTIONAL_CAMERA_SUPPORT
#else
# include "esp_camera.h"
# define OPTIONAL_CAMERA_SUPPORT \
  Y(esp_camera_init, n0 = esp_camera_init((camera_config_t *) a0)) \
  Y(esp_camera_deinit, PUSH esp_camera_deinit()) \
  Y(esp_camera_fb_get, PUSH esp_camera_fb_get()) \
  Y(esp_camera_fb_return, esp_camera_fb_return((camera_fb_t *) a0); DROP) \
  Y(esp_camera_sensor_get, PUSH esp_camera_sensor_get())
#endif

#ifndef ENABLE_SOCKETS_SUPPORT
# define OPTIONAL_SOCKETS_SUPPORT
#else
# include <errno.h>
# include <sys/select.h>
# include <sys/socket.h>
# include <sys/time.h>
# include <sys/types.h>
# include <sys/un.h>
# include <sys/poll.h>
# define OPTIONAL_SOCKETS_SUPPORT \
  Y(socket, n0 = socket(n2, n1, n0); NIPn(2)) \
  Y(bind, n0 = bind(n2, (struct sockaddr *) a1, n0); NIPn(2)) \
  Y(listen, n0 = listen(n1, n0); NIP) \
  Y(connect, n0 = connect(n2, (struct sockaddr *) a1, n0); NIPn(2)) \
  Y(accept, n0 = accept(n2, (struct sockaddr *) a1, (socklen_t *) a0); NIPn(2)) \
  Y(select, n0 = select(n4, (fd_set *) a3, (fd_set *) a2, (fd_set *) a1, (struct timeval *) a0); NIPn(4)) \
  Y(poll, n0 = poll((struct pollfd *) a2, (nfds_t) n1, n0); NIPn(2)) \
  Y(errno, PUSH errno)
#endif

#ifndef ENABLE_SDCARD_SUPPORT
# define OPTIONAL_SDCARD_SUPPORT
#else
# include "SD_MMC.h"
# define OPTIONAL_SDCARD_SUPPORT \
  X("SD_MMC.begin", SD_MMC_BEGIN, tos = SD_MMC.begin(c1, n0); NIP) \
  X("SD_MMC.end", SD_MMC_END, SD_MMC.end()) \
  X("SD_MMC.cardType", SD_MMC_CARD_TYPE, PUSH SD_MMC.cardType()) \
  X("SD_MMC.totalBytes", SD_MMC_TOTAL_BYTES, PUSH SD_MMC.totalBytes()) \
  X("SD_MMC.usedBytes", SD_MMC_USED_BYTES, PUSH SD_MMC.usedBytes())
#endif

#ifndef ENABLE_I2C_SUPPORT
# define OPTIONAL_I2C_SUPPORT
#else
# include <Wire.h>
# define OPTIONAL_I2C_SUPPORT \
  X("Wire.begin", WIRE_BEGIN, n0 = Wire.begin(n1, n0); NIP) \
  X("Wire.setClock", WIRE_SET_CLOCK, Wire.setClock(n0); DROP) \
  X("Wire.getClock", WIRE_GET_CLOCK, PUSH Wire.getClock()) \
  X("Wire.setTimeout", WIRE_SET_TIMEOUT, Wire.setTimeout(n0); DROP) \
  X("Wire.getTimeout", WIRE_GET_TIMEOUT, PUSH Wire.getTimeout()) \
  X("Wire.beginTransmission", WIRE_BEGIN_TRANSMISSION, Wire.beginTransmission(n0); DROP) \
  X("Wire.endTransmission", WIRE_END_TRANSMISSION, SET Wire.endTransmission(n0)) \
  X("Wire.requestFrom", WIRE_REQUEST_FROM, n0 = Wire.requestFrom(n2, n1, n0); NIPn(2)) \
  X("Wire.write", WIRE_WRITE, n0 = Wire.write(b1, n0); NIP) \
  X("Wire.available", WIRE_AVAILABLE, PUSH Wire.available()) \
  X("Wire.read", WIRE_READ, PUSH Wire.read()) \
  X("Wire.peek", WIRE_PEEK, PUSH Wire.peek()) \
  X("Wire.flush", WIRE_FLUSH, Wire.flush())
#endif

#ifndef ENABLE_SERIAL_BLUETOOTH_SUPPORT
# define OPTIONAL_SERIAL_BLUETOOTH_SUPPORT
#else
# include "esp_bt_device.h"
# include "BluetoothSerial.h"
# define bt0 ((BluetoothSerial *) a0)
# define OPTIONAL_SERIAL_BLUETOOTH_SUPPORT \
  X("SerialBT.new", SERIALBT_NEW, PUSH new BluetoothSerial()) \
  X("SerialBT.delete", SERIALBT_DELETE, delete bt0; DROP) \
  X("SerialBT.begin", SERIALBT_BEGIN, n0 = bt0->begin(c2, n1); NIPn(2)) \
  X("SerialBT.end", SERIALBT_END, bt0->end(); DROP) \
  X("SerialBT.available", SERIALBT_AVAILABLE, n0 = bt0->available()) \
  X("SerialBT.readBytes", SERIALBT_READ_BYTES, n0 = bt0->readBytes(b2, n1); NIPn(2)) \
  X("SerialBT.write", SERIALBT_WRITE, n0 = bt0->write(b2, n1); NIPn(2)) \
  X("SerialBT.flush", SERIALBT_FLUSH, bt0->flush(); DROP) \
  X("SerialBT.hasClient", SERIALBT_HAS_CLIENT, n0 = bt0->hasClient()) \
  X("SerialBT.enableSSP", SERIALBT_ENABLE_SSP, bt0->enableSSP(); DROP) \
  X("SerialBT.setPin", SERIALBT_SET_PIN, n0 = bt0->setPin(c1); NIP) \
  X("SerialBT.unpairDevice", SERIALBT_UNPAIR_DEVICE, \
      n0 = bt0->unpairDevice(b1); NIP) \
  X("SerialBT.connect", SERIALBT_CONNECT, n0 = bt0->connect(c1); NIP) \
  X("SerialBT.connectAddr", SERIALBT_CONNECT_ADDR, n0 = bt0->connect(b1); NIP) \
  X("SerialBT.disconnect", SERIALBT_DISCONNECT, n0 = bt0->disconnect()) \
  X("SerialBT.connected", SERIALBT_CONNECTED, n0 = bt0->connected(n1); NIP) \
  X("SerialBT.isReady", SERIALBT_IS_READY, n0 = bt0->isReady(n2, n1); NIPn(2)) \
  /* Bluetooth */ \
  Y(esp_bt_dev_get_address, PUSH esp_bt_dev_get_address())
#endif

#ifndef ENABLE_WIFI_SUPPORT
# define OPTIONAL_WIFI_SUPPORT
#else
# include <WiFi.h>
# include <WiFiClient.h>

static IPAddress ToIP(cell_t ip) {
  return IPAddress(ip & 0xff, ((ip >> 8) & 0xff), ((ip >> 16) & 0xff), ((ip >> 24) & 0xff));
}

static cell_t FromIP(IPAddress ip) {
  cell_t ret = 0;
  ret = (ret << 8) | ip[3];
  ret = (ret << 8) | ip[2];
  ret = (ret << 8) | ip[1];
  ret = (ret << 8) | ip[0];
  return ret;
}

# define OPTIONAL_WIFI_SUPPORT \
  /* WiFi */ \
  X("WiFi.config", WIFI_CONFIG, \
      WiFi.config(ToIP(n3), ToIP(n2), ToIP(n1), ToIP(n0)); DROPn(4)) \
  X("WiFi.begin", WIFI_BEGIN, WiFi.begin(c1, c0); DROPn(2)) \
  X("WiFi.disconnect", WIFI_DISCONNECT, WiFi.disconnect()) \
  X("WiFi.status", WIFI_STATUS, PUSH WiFi.status()) \
  X("WiFi.macAddress", WIFI_MAC_ADDRESS, WiFi.macAddress(b0); DROP) \
  X("WiFi.localIP", WIFI_LOCAL_IPS, PUSH FromIP(WiFi.localIP())) \
  X("WiFi.mode", WIFI_MODE, WiFi.mode((wifi_mode_t) n0); DROP) \
  X("WiFi.setTxPower", WIFI_SET_TX_POWER, WiFi.setTxPower((wifi_power_t) n0); DROP) \
  X("WiFi.getTxPower", WIFI_GET_TX_POWER, PUSH WiFi.getTxPower()) \
  X("WiFi.softAP", wifi_softap, WiFi.begin("superexp", "Thoushal"))
#endif

#ifndef ENABLE_MDNS_SUPPORT
# define OPTIONAL_MDNS_SUPPORT
#else
# include <ESPmDNS.h>
# define OPTIONAL_MDNS_SUPPORT \
  /* mDNS */ \
  X("MDNS.begin", MDNS_BEGIN, n0 = MDNS.begin(c0))
#endif

#ifndef ENABLE_WEBSERVER_SUPPORT
# define OPTIONAL_WEBSERVER_SUPPORT
#else
# include <WebServer.h>
# define ws0 ((WebServer *) a0)
# define OPTIONAL_WEBSERVER_SUPPORT \
  /* WebServer */ \
  X("WebServer.new", WEBSERVER_NEW, PUSH new WebServer(tos)) \
  X("WebServer.delete", WEBSERVER_DELETE, delete ws0; DROP) \
  X("WebServer.begin", WEBSERVER_BEGIN, ws0->begin(n1); DROPn(2)) \
  X("WebServer.stop", WEBSERVER_STOP, ws0->stop(); DROP) \
  X("WebServer.on", WEBSERVER_ON, InvokeWebServerOn(ws0, c2, n1); DROPn(3)) \
  X("WebServer.hasArg", WEBSERVER_HAS_ARG, n0 = ws0->hasArg(c1); DROP) \
  X("WebServer.arg", WEBSERVER_ARG, \
      string_value = ws0->arg(c1); \
      c1 = &string_value[0]; n0 = string_value.length()) \
  X("WebServer.argi", WEBSERVER_ARGI, \
      string_value = ws0->arg(n1); \
      c1 = &string_value[0]; n0 = string_value.length()) \
  X("WebServer.argName", WEBSERVER_ARG_NAME, \
      string_value = ws0->argName(n1); \
      c1 = &string_value[0]; n0 = string_value.length()) \
  X("WebServer.args", WEBSERVER_ARGS, n0 = ws0->args()) \
  X("WebServer.setContentLength", WEBSERVER_SET_CONTENT_LENGTH, \
      ws0->setContentLength(n1); DROPn(2)) \
  X("WebServer.sendHeader", WEBSERVER_SEND_HEADER, \
      ws0->sendHeader(c3, c2, n1); DROPn(4)) \
  X("WebServer.send", WEBSERVER_SEND, ws0->send(n3, c2, c1); DROPn(4)) \
  X("WebServer.sendContent", WEBSERVER_SEND_CONTENT, \
      ws0->sendContent(c1); DROPn(2)) \
  X("WebServer.method", WEBSERVER_METHOD, n0 = ws0->method()) \
  X("WebServer.handleClient", WEBSERVER_HANDLE_CLIENT, ws0->handleClient(); DROP)
#endif
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
void loop() {
  g_sys.rp = forth_run(g_sys.rp);
}

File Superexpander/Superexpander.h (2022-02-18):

struct InputRegister
{
  byte unused;
  byte counter1; 
  byte counter2;
  byte sensors;   //8 on-off sensors
} input_register;

class Superexpander
{
    const int p2s_data_pin = 23; // Connect Pin 11 to SER_OUT (Serial data out) - Pin 9 (Q7) of 74HC165
    const int p2s_shld_pin = 19; // Connect Pin 8 to SH/!LD (shift or active low load) - Pin 1 (!PL) of 74HC165
    const int p2s_clk_pin = 17; // Connect Pin 12 to CLK (the clock that times the shifting) - Pin 2 (CP) of 74HC165
    const int p2s_ce_pin = 18; // Connect Pin 9 to !CE (clock enable, active low) - Pin 15 (!CE) of 74HC165
    const int counter_reset_pin = 13;
    const int s2p_sda_pin = 4;
    const int s2p_scl_pin = 17;
    const int s2p_latch_pin = 16;

    uint16_t output_register = 0; // 16 on-off output switches

  protected:

    uint32_t shiftInN(int sda, int sck, boolean xsb, int nBits)
    {
      uint32_t rv;
      rv = 0;

      for (int i = 0; i < nBits; i++) {
        digitalWrite(sck, HIGH);
        delayMicroseconds(5);
        int b = digitalRead(sda);
        if (xsb == MSBFIRST) {
          rv |= b << i;
        } else {
          rv |= b << (nBits - i);
        }
        digitalWrite(sck, LOW);
        delayMicroseconds(5);
      }

      return rv;
    }


  public:
    
 
    inline void setSwitch(int n, boolean b)
    {
      if (b)
        output_register |= (1 << n);
      else
        output_register &= ~(1 << n);
    }

    inline void setMotor(boolean left_forward, boolean right_forward)
    {
      if (left_forward){
        setSwitch(0, true);
        setSwitch(1, false);
      } else {
        setSwitch(0, false);
        setSwitch(1, true);
      }
      if (right_forward){
        setSwitch(2, true);
        setSwitch(3, false);
      } else {
        setSwitch(2, false);
        setSwitch(3, true);
      }

    }
    
    inline int getCounter1()
    {
      return input_register.counter1;
    }

    inline int getCounter2()
    {
      return input_register.counter2;
    }


   inline bool getSensor(int n)
    {
      return input_register.sensors&(1<<n);
    }
 

    void begin()
    {
      pinMode(p2s_shld_pin, OUTPUT);
      pinMode(p2s_ce_pin, OUTPUT);
      pinMode(p2s_clk_pin, OUTPUT);
      pinMode(p2s_data_pin, INPUT);
      pinMode(counter_reset_pin, OUTPUT);

      pinMode(s2p_sda_pin, OUTPUT);
     // pinMode(s2p_scl_pin, OUTPUT); // Not necessary. Same as p2s_clk_pin
      pinMode(s2p_latch_pin, OUTPUT);

      digitalWrite(counter_reset_pin, HIGH);
      delay(20);
      digitalWrite(counter_reset_pin, LOW);
      // Required initial states of these two pins according to the datasheet timing diagram
      digitalWrite(p2s_clk_pin, HIGH);
      digitalWrite(p2s_shld_pin, HIGH);
      Serial.println("Turnimator Cyberdelix\nSuperexpander v.01 initialized");

    }

    void writeBoard()
    {
      byte hibyte = (output_register >> 8) & 0xff;
      byte lowbyte = output_register & 0xff;

      digitalWrite(s2p_latch_pin, 0);
      shiftOut(s2p_sda_pin, s2p_scl_pin, MSBFIRST, hibyte);
      shiftOut(s2p_sda_pin, s2p_scl_pin, MSBFIRST, lowbyte);
      digitalWrite(s2p_latch_pin, 1);
    }

    void readBoard()
    {

      digitalWrite(p2s_shld_pin, LOW); // Load data
      delayMicroseconds(5);
      digitalWrite(p2s_shld_pin, HIGH);
      delayMicroseconds(5);
      digitalWrite(p2s_clk_pin, HIGH);
      digitalWrite(p2s_ce_pin, LOW); // Enable the clock
      input_register.counter1 = ~shiftIn(p2s_data_pin, p2s_clk_pin, MSBFIRST);
      input_register.counter2 = ~shiftIn(p2s_data_pin, p2s_clk_pin, MSBFIRST);
      input_register.sensors = shiftIn(p2s_data_pin, p2s_clk_pin, MSBFIRST);

      digitalWrite(p2s_ce_pin, HIGH); // Disable the clock
    }

};

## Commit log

2022-02-27 Complete Project
    [ESP32wShiftRegisters-B_Cu.gbr, ESP32wShiftRegisters-Edge_Cuts.gbr, ESP32wShiftRegisters-F_Cu.gbr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]
2022-05-03 Added motor.fs
